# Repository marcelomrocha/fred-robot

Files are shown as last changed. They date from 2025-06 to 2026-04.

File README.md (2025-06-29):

# FRED - Friendly Robot for EDucation and Healthcare
</br></br>
<p align="center">
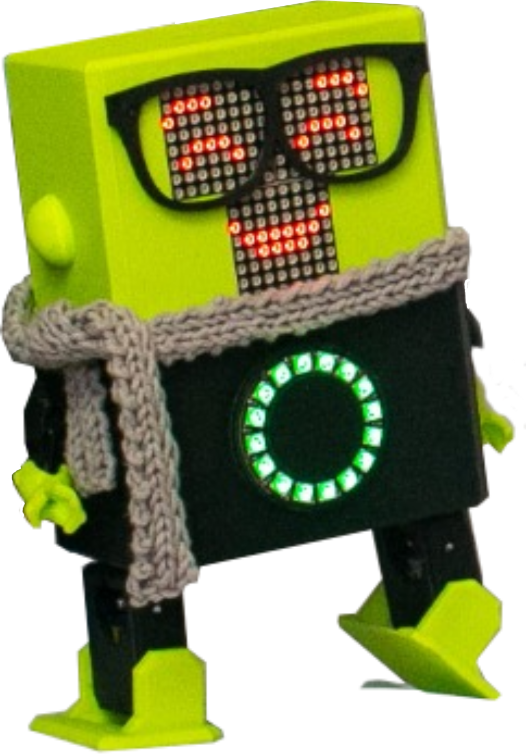
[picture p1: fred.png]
 </br></br>
<strong>Figure 1.</strong> FRED Robot - A Friendly Robot for EDucation and Healthcare.
</p>
</br></br></br>
<p align="center">
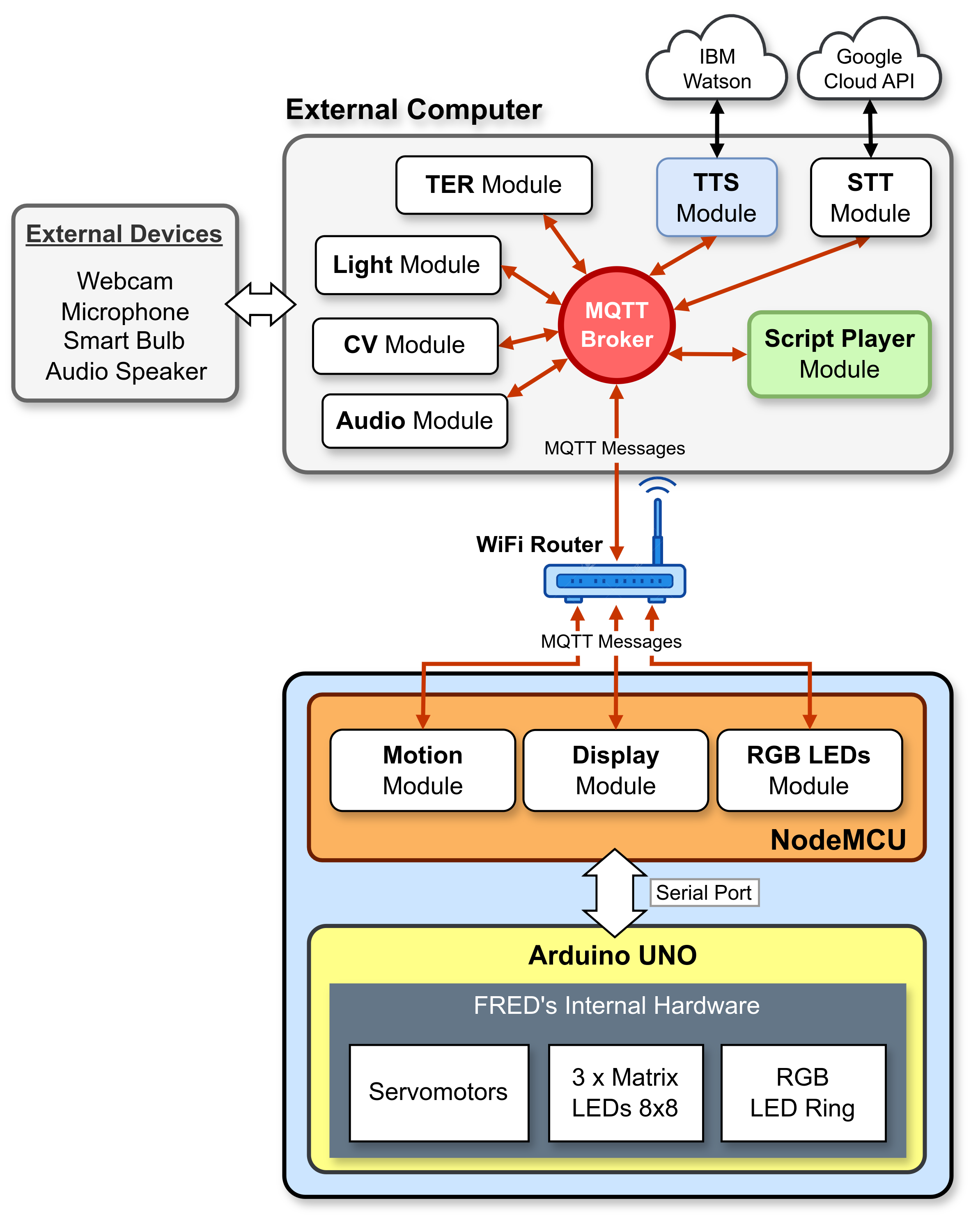
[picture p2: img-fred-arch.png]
 </br></br>
<strong>Figure 2.</strong> FRED Robot - Software Archtecture.

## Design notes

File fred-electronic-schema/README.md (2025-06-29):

# FRED - Friendly Robot for EDucation and Healthcare
## Electronic Schema Using an Arduino and ESP8266 Boards

Figure 1 shows the connection diagram for the FRED hardware components using jumper wires and a mini protoboard. The battery shown in the figure represents the 5V power supply with a minimum current capacity of 2A. All power for the FRED internal hardware system is supplied by this power supply. The diagram shown in the figure shows that the 8x8 LED arrays that make up the robot's display are connected in cascade (in series). The information for the LEDs in each array is sent through a multiplexing process, preventing the need for multiple Arduino ports to control the robot's display. The same happens with the ring of 16 RGB LEDs, whose LEDs are individually controlled by just one port on the Arduino board. The figure also shows the 4 servomotors with the indication of each one, whether it is on the left or right leg or whether it is on the right or left foot.

Recently, three **TTP223** touch sensors were added to the FRED robotics platform. These sensors were attached to the robot’s internal surfaces, on the top of its head and below both ears. Now, touching the top of FRED’s head, right in the center, for about five seconds causes the robot to look in love, turn on its LEDs in rainbow mode, and pose with its legs "broken", indicating that it has fallen in love after receiving the user’s affection. If the user also touches the area just below FRED's ears for about five seconds, the robot will smile, turn on its LEDs green and bend its right or left foot, respectively, indicating that it felt tickled by the user. In the three previous cases, after contact with the user, the robot returns to the neutral position, with a neutral look and its LEDs off (without color).

**For testing purposes only**, initially, just to test the firmware and connections, the power can come directly from the Arduino's 5V pin, with the Arduino connected to the computer's USB port.

</br>
<p align="center">
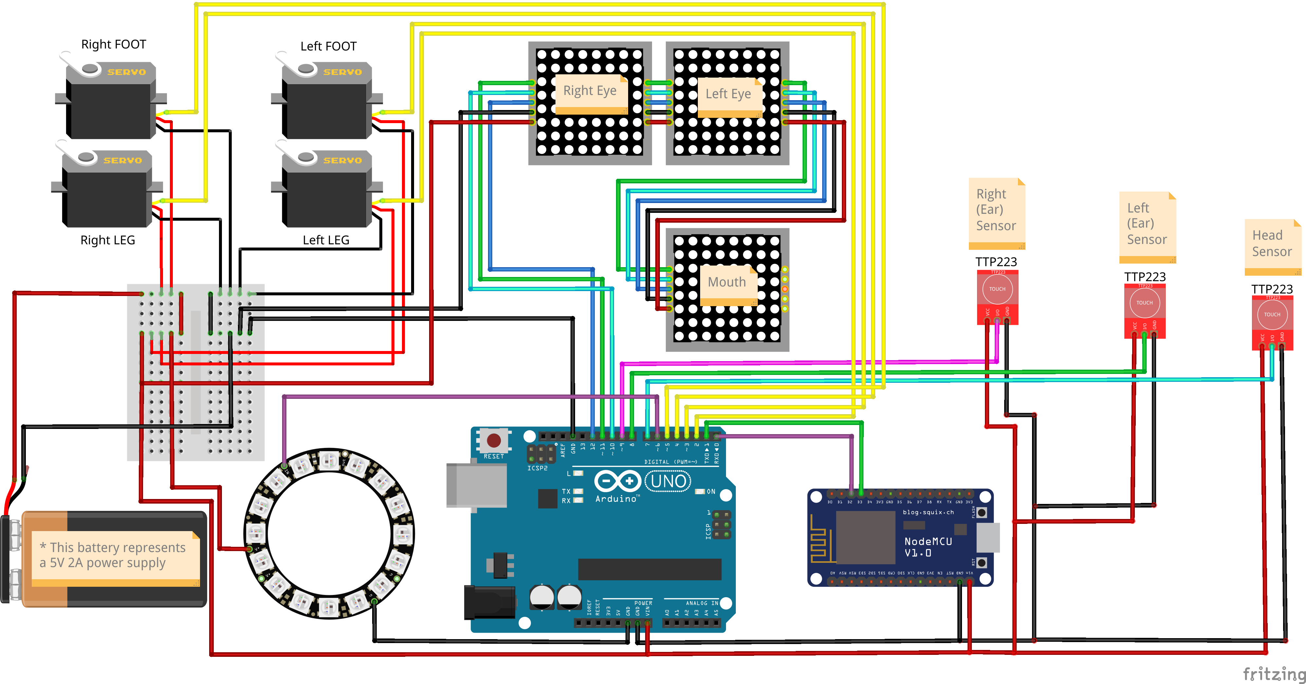
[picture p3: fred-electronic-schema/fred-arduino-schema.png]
 </br>
<strong>Figure 1.</strong> FRED Robot - Electronic Schema
</p>

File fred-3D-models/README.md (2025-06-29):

## FRED Robot - 3D parts description

Figure 1 shows the 3D models of FRED rendered in TinkerCad. Item (1) shows the 3D part of FRED's head. Item (2) shows the cover of the back of the head. Item (3) is the robot's chest. The version in the image is equivalent to the chest of the female version made to receive the pink heart. Item (4) shows the cover of the back of the chest. Item (5) shows the shoulder that must be screwed to the chest. Items (6) and (7) are, respectively, the arm and articulated hand of the robot. There is no difference between the shoulders, arms and left and right hands. Items (8) and (9) are the right and left feet. It is important to note that there is a difference between the left and right foot models. In (10) you can see two pieces of the robot's legs. These pieces use the same model, with no difference between the left and right legs. In (11) you can see the model of FRED's glasses. And finally, in item (12) you can see the model of the female glasses and the 3D heart piece that can be fitted to the female chest model.

It is important to note that in this directory there are two head models (FRED and Frida) that differ only in the size of the ears and there are two chest models (FRED and Frida). There is also a model for the 3D piece used on the female head to attach Frida's bows.

If you want to customize any element or use these models as a basis for your project, you can access them through this <a href="https://www.tinkercad.com/things/dGqDeysEWR8-copy-of-projeto-fred-versao-2023/edit" target="_blank">link</a>.

</br>
<p align="center">
 </br>
<strong>Figure 1.</strong> FRED Robot - 3D parts rendered
</p>

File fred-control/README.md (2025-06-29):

# FRED - Friendly Robot for EDucation and Healthcare
## FRED's Arduino Control Software

The software architecture of the FRED robot can be divided into two layers, high-level and low-level. The low-level layer is implemented on the Arduino UNO and ESP8266 (NodeMCU) boards inside the robot. The control software for this layer is divided into these two boards. The software running on the Arduino board is responsible for controlling and communicating with the robot's actuators, such as: the three LED arrays that represent the robot's facial expression, the RGB LED strip on the robot's chest, and the four servomotors that make up FRED's legs and feet.

</br>
<p align="center">
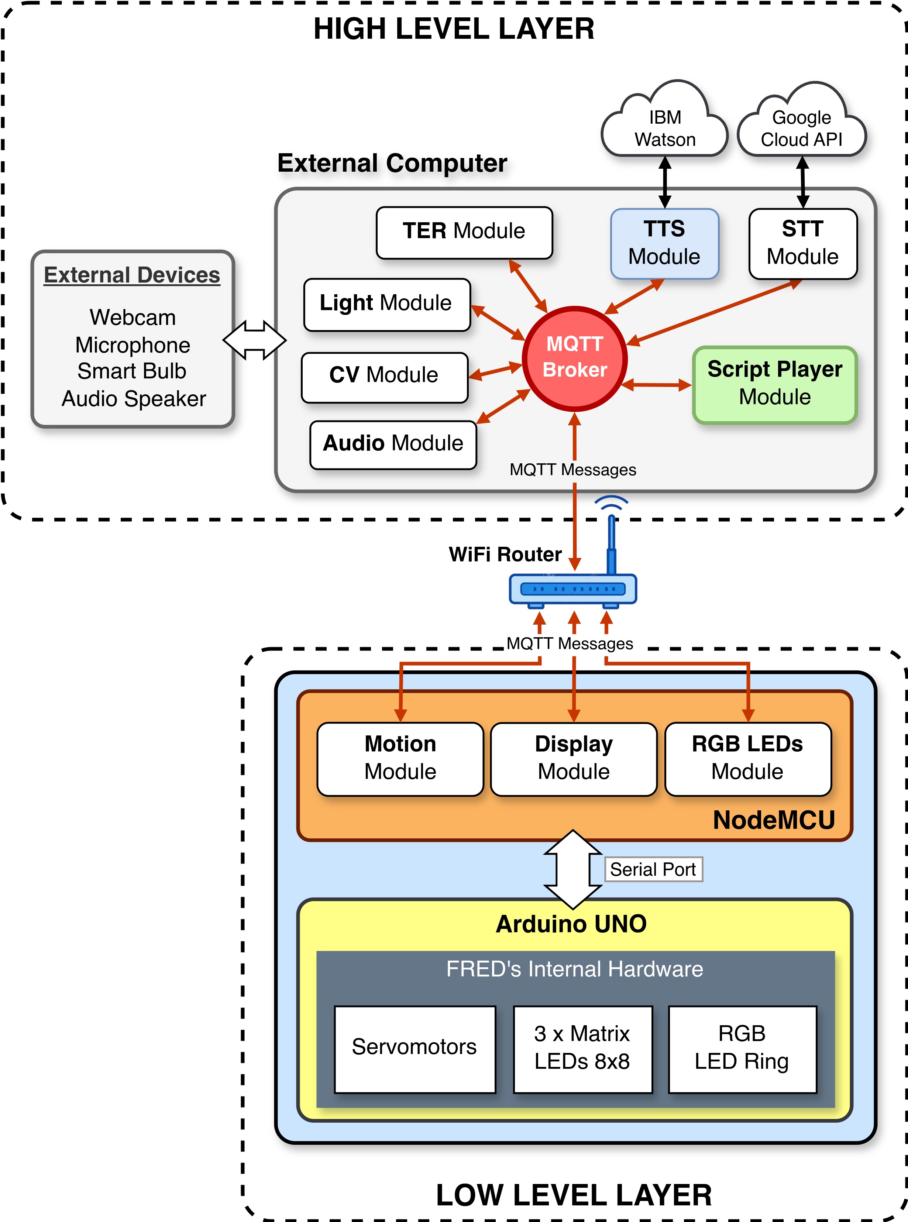
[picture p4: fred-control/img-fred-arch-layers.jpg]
 </br></br>
<strong>Figure 1.</strong> FRED Robot - Software Archtecture (LAYERS).
</br></br></br>

The FRED firmware for the Arduino board depends on two libraries, **VarSpeedServo (4)**, **LedControl (3)** and **Adafruit_NeoPixel (2)**. They are, respectively, the libraries that control the servomotors and the LED ring on the robot's chest. These libraries must be inside the **libraries folder (1)** of the Arduino IDE. These libraries are available in this directory in a compressed form. You must download the three compressed files and unzip them in the IDE's **libraries folder (1)**, as you can see in Figure 2.

</br>
<p align="center">
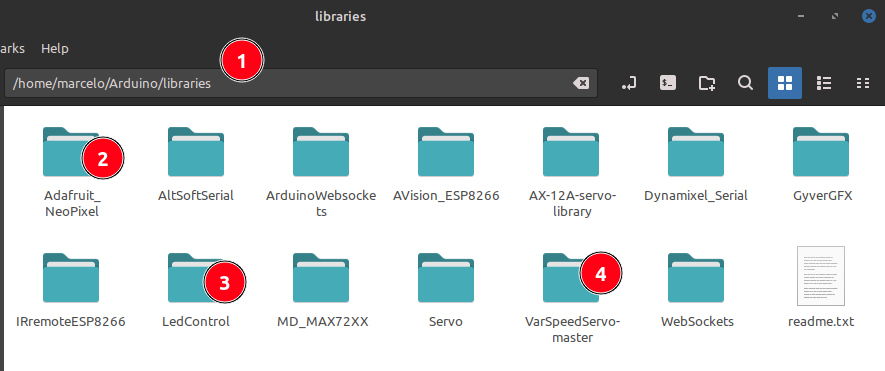
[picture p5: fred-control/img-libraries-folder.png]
 </br></br>
<strong>Figure 2.</strong> Copying and uncompressing the libraries do the Arduino libraries folder.

</br></br>
After that, the **FredControl.ino** file can be loaded into the Arduino IDE, compiled and uploaded to the Arduino UNO board.

As you can see in Figure 3, the necessary libraries are included right at the beginning of the code (1). In (2) there is the inclusion of the files **FredSymbols.h**, which contain the **array of bits** that define the design of FRED's gaze, and the files **FredControlBoy.h** and **FredControlGirl.h**, which contain some adjustments to specific parameters of the FRED and Frida robots.

</br>
<p align="center">
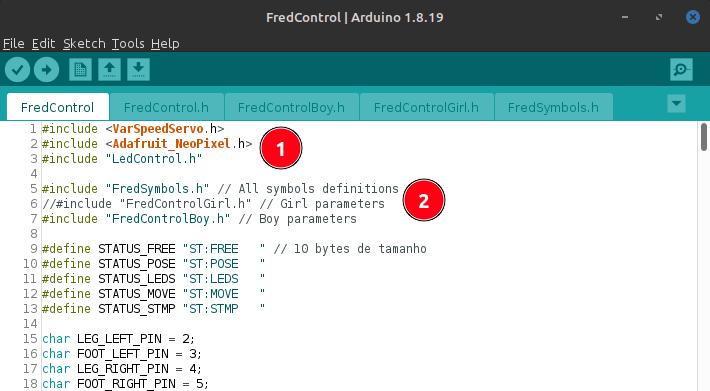
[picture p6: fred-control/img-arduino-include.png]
 </br></br>
<strong>Figure 3.</strong> Files used in Arduino's #include section.

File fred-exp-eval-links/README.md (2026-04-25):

<p align="center">
  FRED Robot
</p>

<h1 align="center">🤖 FRED Robot: Affective Expressions Evaluation</h1>

<p align="center">
  Video stimuli used in the experimental evaluation of the interaction between <b>FRED</b> and <b>Frida</b>.
</p>

<p align="center">
  <i>Low-cost affective social robot for HRI research</i>
</p>

---

> **Note:** GitHub opens links in the same tab by default. Use **Ctrl + Click** or **Cmd + Click** to open videos in a new tab.

## 📺 Video Stimuli

| Content | Access |
| :--- | :--- |
| 🎬 **Complete Interaction Video** |  |
| 🧩 **Video Block 1** |  |
| 🧩 **Video Block 2** |  |
| 🧩 **Video Block 3** |  |
| 🧩 **Video Block 4** |  |
| 🧩 **Video Block 5** |  |
| 🧩 **Video Block 6** |  |

---

## 🧠 Description of the Stimuli

The complete video presents a dialogue between the robots **FRED** and **Frida**. For evaluation purposes, the interaction was segmented into six blocks, each containing one or more affective expressions performed by the FRED robot.

These expressions were generated through the combination of nonverbal communication elements, including facial expressions, body poses, and RGB LED patterns, representing the emotions evaluated in the study: **happiness, sadness, anger, and surprise**, as well as neutral states.

Each video block was used as an independent stimulus during the experiment, allowing participants to assess the perceived intensity of each emotion.

---

## 🔗 Citation

If you use this material, please cite:

```bibtex
@phdthesis{your_reference_here,
  author = {Your Name},
  title = {Your Thesis Title},
  school = {Your Institution},
  year = {2026}
}

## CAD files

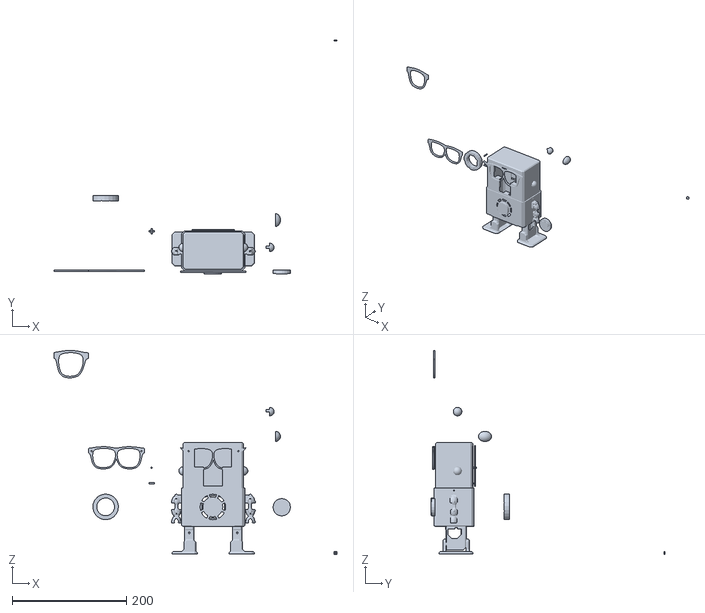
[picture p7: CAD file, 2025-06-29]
fred-3D-models/FRED-ALL-PARTS-24-9-2023.stl
496.0 x 410.0 x 357.6

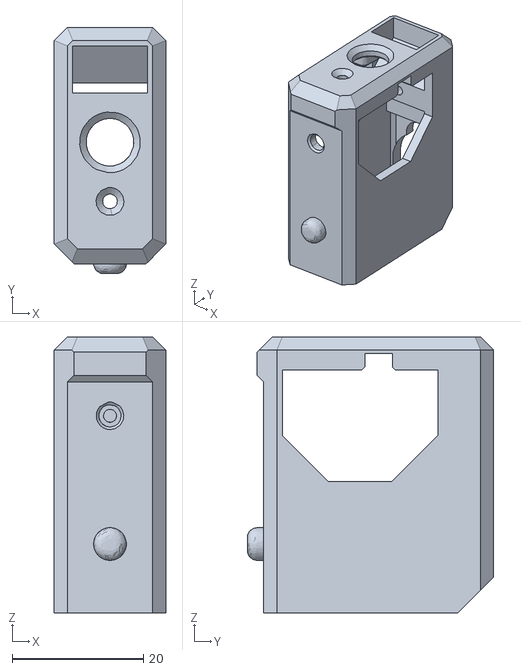
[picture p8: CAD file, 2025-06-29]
fred-3D-models/fred-leg.stl
17.0 x 37.5 x 42.0

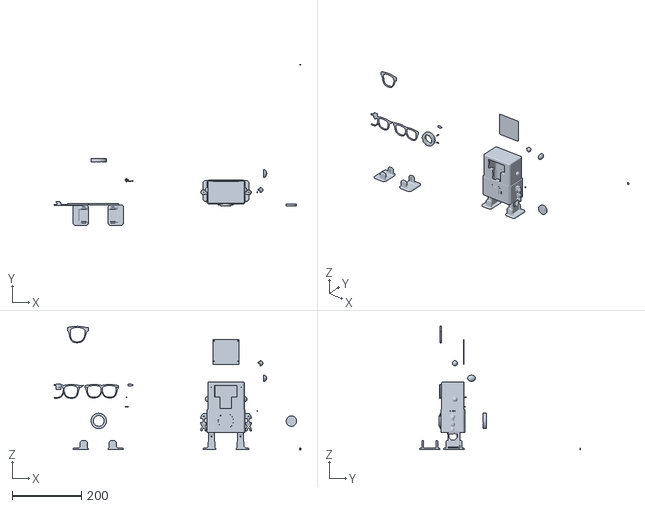
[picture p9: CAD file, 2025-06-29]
fred-3D-models/FRED-ALL-PARTS-30-9-2023.stl
715.0 x 466.2 x 357.6

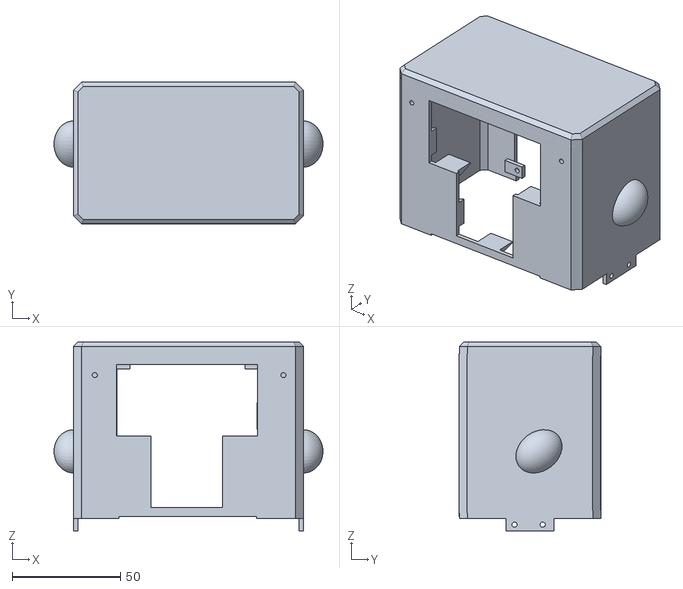
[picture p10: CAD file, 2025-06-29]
fred-3D-models/fred-boy-head.stl
124.1 x 65.4 x 87.1

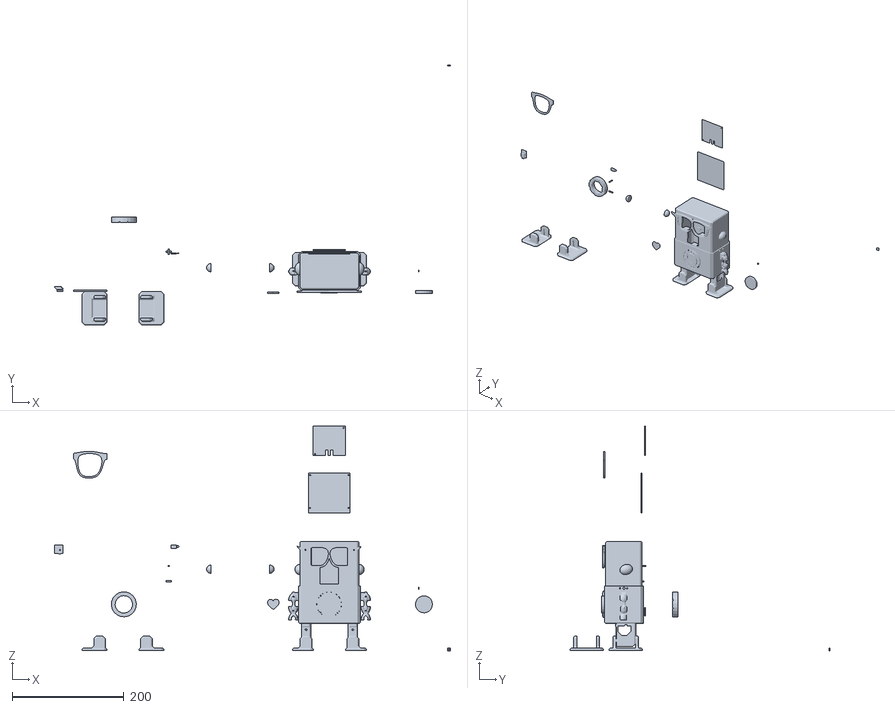
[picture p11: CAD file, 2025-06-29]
fred-3D-models/FRED-ALL-PARTS-02-10-2023.stl
709.8 x 466.2 x 403.0

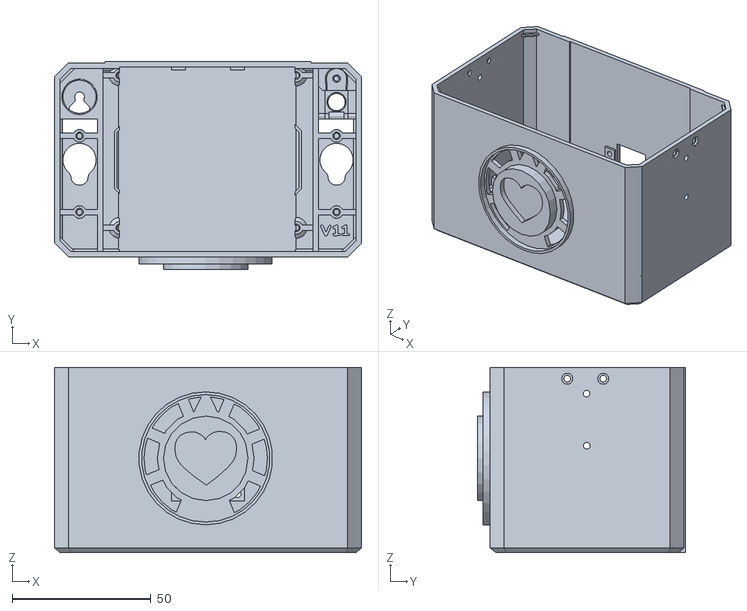
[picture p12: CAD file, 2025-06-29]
fred-3D-models/fred-girl-torax.stl
110.8 x 75.0 x 66.9

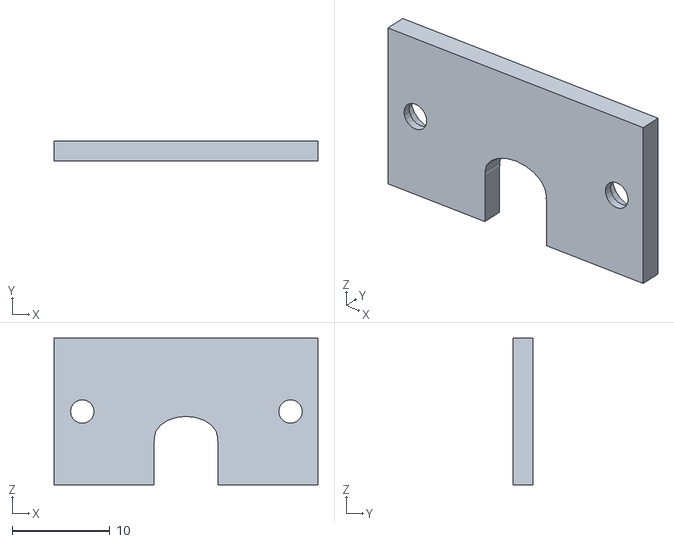
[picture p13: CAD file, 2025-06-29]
fred-3D-models/fred-tampo-torax.stl
27.0 x 2.00 x 15.0

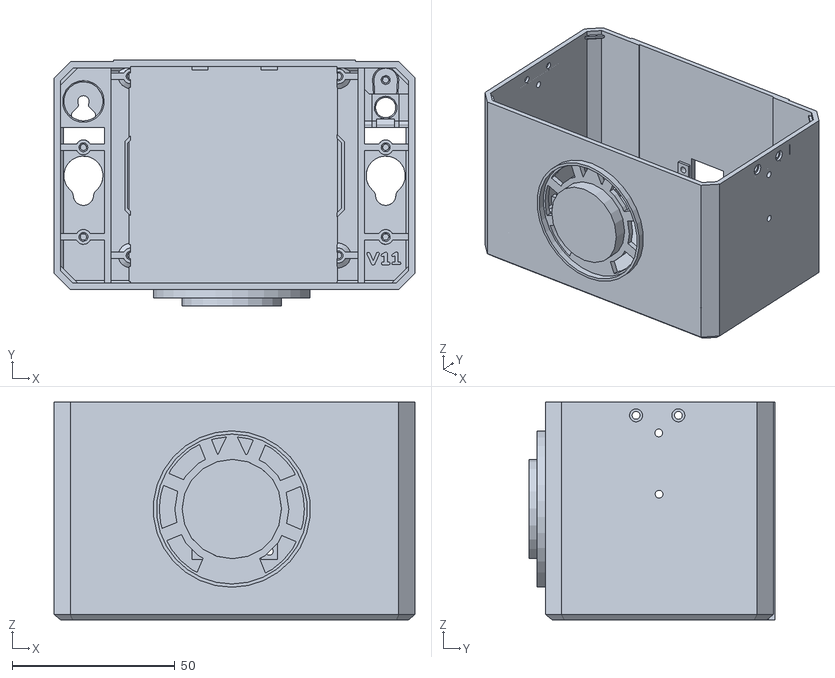
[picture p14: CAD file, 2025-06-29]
fred-3D-models/fred-boy-torax.stl
110.8 x 75.5 x 66.9

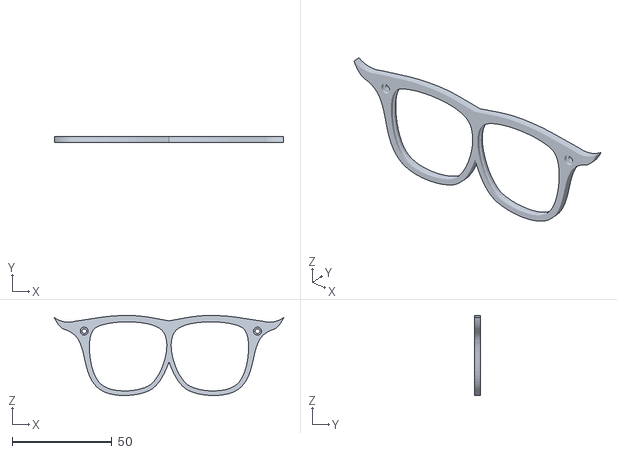
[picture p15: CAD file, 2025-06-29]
fred-3D-models/fred-girl-glasses.stl
115.0 x 3.00 x 40.2

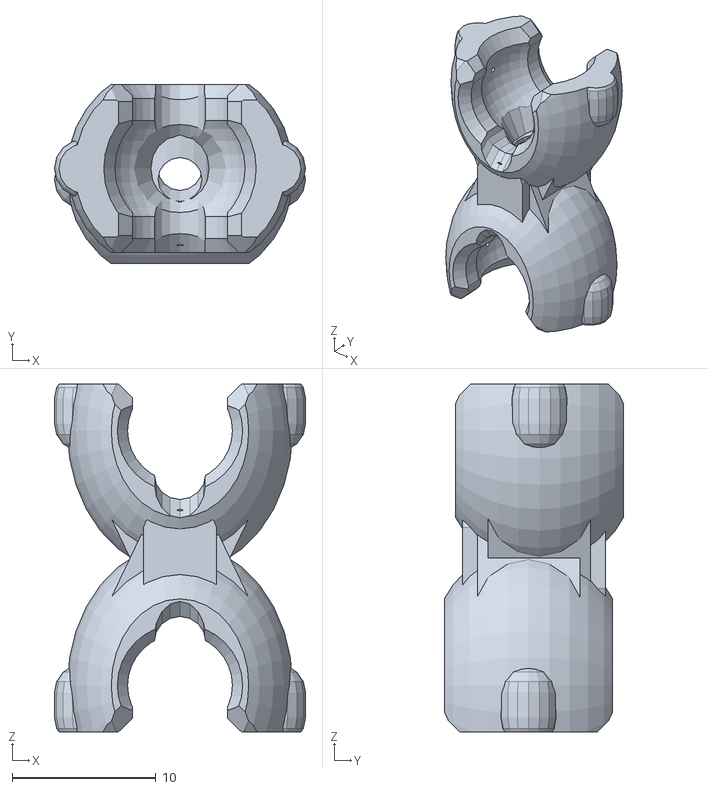
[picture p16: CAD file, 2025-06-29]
fred-3D-models/fred-hand.stl
17.5 x 12.5 x 24.2

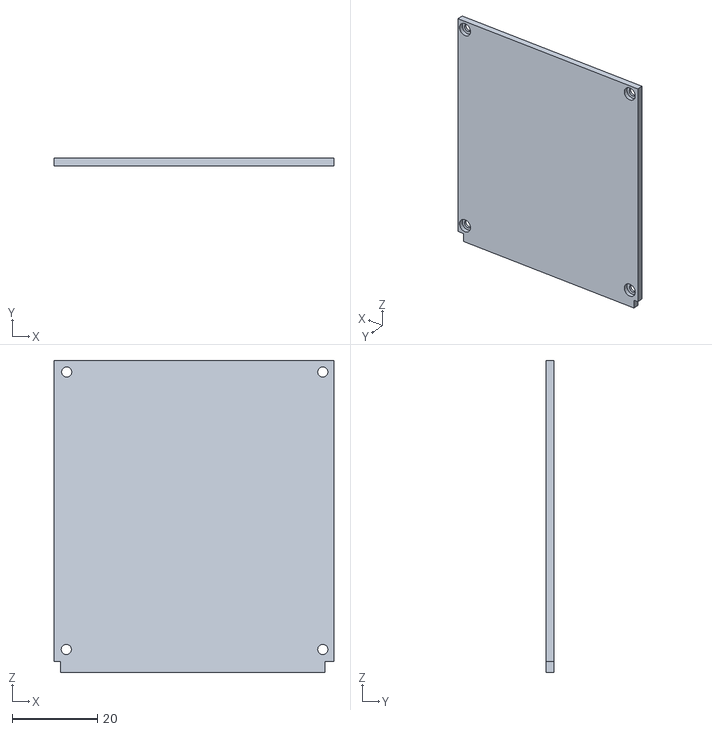
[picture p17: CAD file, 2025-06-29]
fred-3D-models/fred-tampo-head.stl
65.5 x 1.97 x 73.1

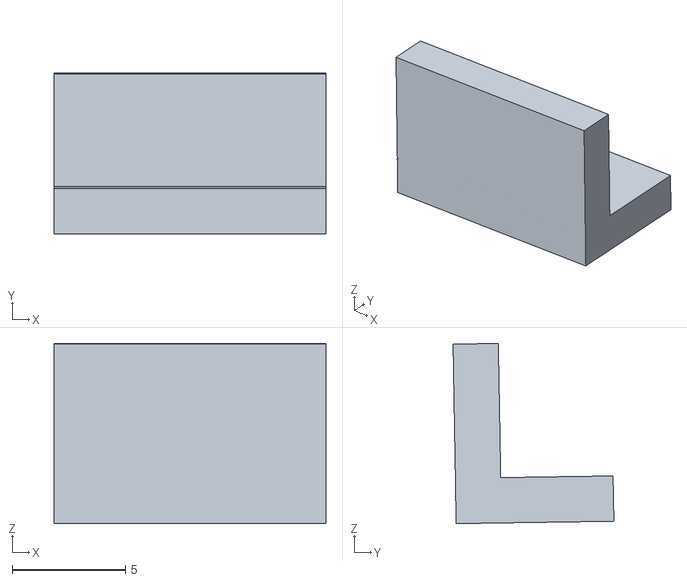
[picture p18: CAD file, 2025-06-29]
fred-3D-models/fred-girl-fixa-grampo.stl
12.0 x 7.10 x 7.95

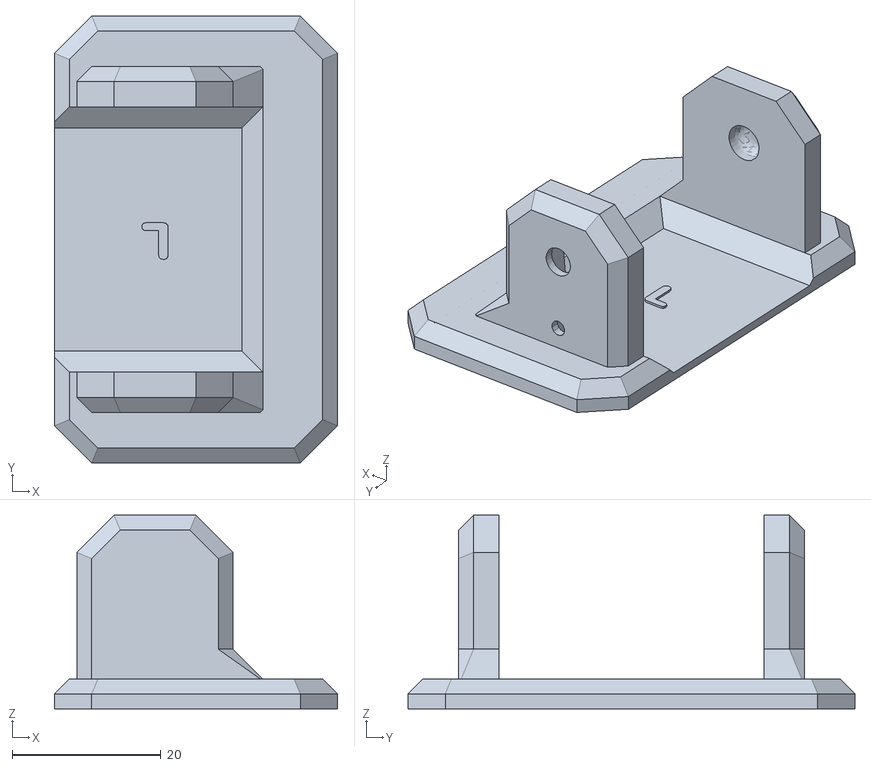
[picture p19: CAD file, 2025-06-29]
fred-3D-models/fred-left-foot-small.stl
38.0 x 60.0 x 26.0

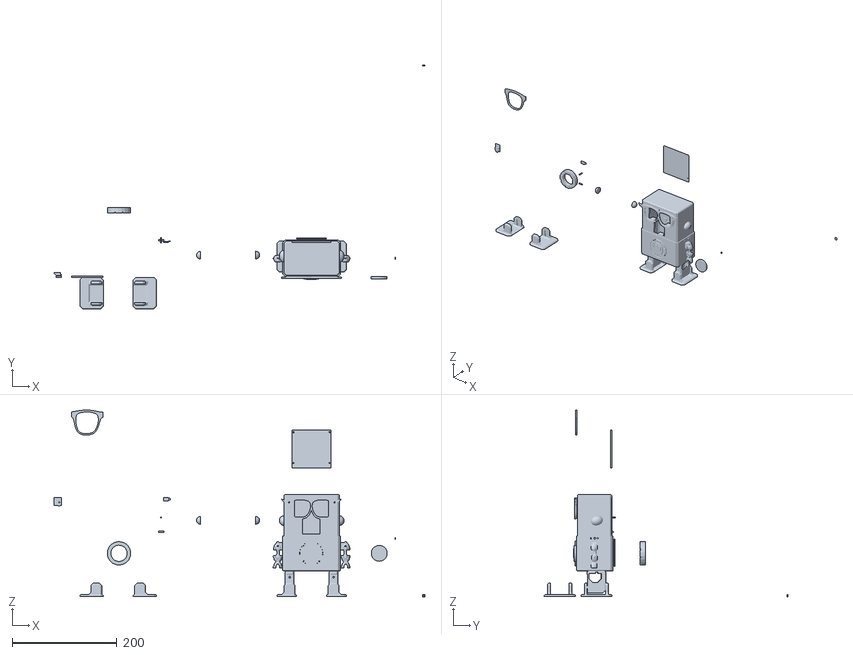
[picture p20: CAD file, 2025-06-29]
fred-3D-models/FRED-ALL-PARTS-01-10-2023.stl
709.8 x 466.2 x 357.6

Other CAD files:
fred-3D-models/fred-girl-heart.stl
fred-3D-models/fred-girl-head.stl
fred-3D-models/fred-shoulder.stl
fred-3D-models/fred-arm.stl
fred-3D-models/fred-boy-glasses.stl
fred-3D-models/fred-right-foot-small.stl

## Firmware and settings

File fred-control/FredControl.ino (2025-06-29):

#include <VarSpeedServo.h>
#include <Adafruit_NeoPixel.h>
#include "LedControl.h"
 
#include "FredSymbols.h" // All symbols definitions
#include "FredControlGirl.h" // Girl parameters
// #include "FredControlBoy.h" // Boy parameters

#define STATUS_FREE "ST:FREE   " // 10 bytes de tamanho
#define STATUS_POSE "ST:POSE   "
#define STATUS_LEDS "ST:LEDS   "
#define STATUS_MOVE "ST:MOVE   "
#define STATUS_STMP "ST:STMP   "

char LEG_LEFT_PIN = 2;
char FOOT_LEFT_PIN = 3;
char LEG_RIGHT_PIN = 4;
char FOOT_RIGHT_PIN = 5;

// Sensores de toque
int TOUCH_HEAD_PIN = 7;
int TOUCH_HEAD_VALUE = 0;
int TOUCH_LEFT_PIN = 8;
int TOUCH_LEFT_VALUE = 0;
int TOUCH_RIGHT_PIN = 9;
int TOUCH_RIGHT_VALUE = 0;

// variaveis de estado do robô
char veloc_srv = 40; // servo movement velocity
char state_pose = NULL; // estado da posição inicial
char state_expression = NULL; // estado da expressão (display) inicial
char state_exp_aux = NULL; // variavel mantem seu estado mesmo depois da funcao terminar
char state_led = NULL; // estado do anel de leds

unsigned long eye_blinking_mills = millis(); // eye blinking
unsigned long eye_blinking_delay = 5000; // delay eye blinking
unsigned long foot_mills = millis(); // foot effect
unsigned long foot_delay = 5000; // delay foot effect
unsigned long led_speech_mills = millis(); // LED speech effect
unsigned long led_speech_delay = 400; // LED speech delay effect

VarSpeedServo leg_left_srv;
VarSpeedServo foot_left_srv;
VarSpeedServo leg_right_srv;
VarSpeedServo foot_right_srv;

/*
 Now we need a LedControl to work with.
 ***** These pin numbers will probably not work with your hardware *****
 pin 12 is connected to the DataIn (azul ou verde)
 pin 11 is connected to the CLK     (cinza ou marron)
 pin 10 is connected to LOAD    (branco ou laranja)
 We have 3  MAX72XX.
 */
LedControl lc=LedControl(12,11,10,3);
int delay_leds = 200; // determina a velocidade do efeito dos leds. Quanto maior o valor mais lento.

// defining expressions vars
Expression fred;
Expression in_love;
Expression broken;
Expression neutral;
Expression pleased;
Expression happy;
Expression sad;
Expression angry, angry2;
Expression surprised, surprised2;
Expression afraid;

// Parameter 1 = number of pixels in strip
// Parameter 2 = pin number (most are valid)
// Parameter 3 = pixel type flags, add together as needed:
//   NEO_KHZ800  800 KHz bitstream (most NeoPixel products w/WS2812 LEDs)
//   NEO_KHZ400  400 KHz (classic 'v1' (not v2) FLORA pixels, WS2811 drivers)
//   NEO_GRB     Pixels are wired for GRB bitstream (most NeoPixel products)
//   NEO_RGB     Pixels are wired for RGB bitstream (v1 FLORA pixels, not v2)

#define PIN 6
Adafruit_NeoPixel ring = Adafruit_NeoPixel(16, PIN, NEO_GRB + NEO_KHZ800);
 

void setup() {

  Serial.begin(9600);

  pinMode(TOUCH_HEAD_PIN, INPUT);
  pinMode(TOUCH_LEFT_PIN, INPUT);
  pinMode(TOUCH_RIGHT_PIN, INPUT);

  fred.right_eye = fr;
  fred.left_eye = ed;
  fred.mouth = heart;

  in_love.right_eye = r_eye_in_love;
  in_love.left_eye = l_eye_in_love;
  in_love.mouth = m_in_love;

  broken.right_eye = r_eye_broken;
  broken.left_eye = l_eye_in_broken;
  broken.mouth = m_in_broken;

  neutral.right_eye = r_eye_neutral;
  neutral.left_eye = l_eye_neutral;
  neutral.mouth = m_neutral;

  pleased.right_eye = r_eye_pleased;
  pleased.left_eye = l_eye_pleased;
  pleased.mouth = m_pleased;

  happy.right_eye = r_eye_happy;
  happy.left_eye = l_eye_in_happy;
  happy.mouth = m_in_happy;

  sad.right_eye = r_eye_sad;
  sad.left_eye = l_eye_in_sad;
  sad.mouth = m_in_sad;

  angry.right_eye = r_eye_angry;
  angry.left_eye = l_eye_in_angry;
  angry.mouth = m_in_angry;

  angry2.right_eye = r_eye_angry2;
  angry2.left_eye = l_eye_in_angry2;
  angry2.mouth = m_in_angry2;

  surprised.right_eye = r_eye_surprised;
  surprised.left_eye = l_eye_in_surprised;
  surprised.mouth = m_in_surprised;

  surprised2.right_eye = r_eye_surprised;
  surprised2.left_eye = l_eye_in_surprised;
  surprised2.mouth = m_in_surprised2;

  afraid.right_eye = r_eye_afraid;
  afraid.left_eye = l_eye_in_afraid;
  afraid.mouth = m_in_afraid;
  
    /*
   The MAX72XX is in power-saving mode on startup,
   we have to do a wakeup call
   */
  lc.shutdown(0,false);
  lc.shutdown(1,false);
  lc.shutdown(2,false);
  /* Set the brightness to a medium values */
  lc.setIntensity(0,1);
  lc.setIntensity(1,1);
  lc.setIntensity(2,1);
  /* and clear the display */
  lc.clearDisplay(0);
  lc.clearDisplay(1);
  lc.clearDisplay(2);

  ring.begin();
  ring.setBrightness(5); //adjust brightness here
  ring.show(); // Initialize all pixels to 'off'
  
  expression_show(fred); 
  delay(3000);
  colorWipe(ring.Color(255, 0, 0), delay_leds, 'r'); // Black (off)
  state_led = 'r';
  expression_show(broken);
  state_expression = 'b';
  servos_attach();
  pose_init('1');
}
 
void loop() {
  run();
}

///////////////////////////////////////////////////////////////// Função principal que roda as outras funções //////////////////////////
// looping principal
void run(){
  while (1){
    processa_serial_port(); // 
    blinking_eyes(); // pisca olhos aleatoreamente
    anim_feet(); // move os pés do FRED aleatoreamente
    sense_touch(); // Verifica se o robo foi tocado e muda o seu estado, executando a animaçao
  }
}


///////////////////////////////////////////////////////////////// Funções para os LEDs RGB ////////////////////////////////////////
// Fill the dots one after the other with a color
void colorWipe(uint32_t c, uint8_t wait, char type) {
  if (state_expression == 'T') {
    state_led = type;
    servos_attach();
  }
  else {
    servos_detach();
    delay(1); // evita o truncamento no envio pela porta serial
    //Serial.print(STATUS_LEDS);
    for(uint16_t i=0; i<ring.numPixels() / 4 + 1; i++) {
      ring.setPixelColor(4 - i, c);
      ring.setPixelColor(4 + i, c);
      ring.setPixelColor(12 - i, c);
      ring.setPixelColor(12 + i, c);
      ring.show();
      delay(wait);
//      blinking_eyes();
    }
    delay(1);
    //Serial.print(STATUS_FREE);
  }
  state_led = type;
  servos_attach();
}

// efeito no LED usado na fala do robô
void colorSpeech(uint32_t c, bool type) {
  servos_detach();
  if (type == false){ // acende os LEDS pares
    for(uint16_t i=0; i<=ring.numPixels(); i++) {
        if (i % 3 == 0){
          ring.setPixelColor(i, c);
//          ring.show();
        }
        else {
          ring.setPixelColor(i, (0, 0, 0));
//          ring.show();
        }
        ring.show();
    }
  }
  else { // acende os LEDs ímpares
    for(uint16_t i=0; i<=ring.numPixels(); i++) {
        if (i % 3 != 0){
          ring.setPixelColor(i, c);
        }
        else {
          ring.setPixelColor(i, (0, 0, 0));
        }
        ring.show();
    }
  }
}
 

void rainbow(uint8_t wait, char type) {
  servos_detach();
  delay(1); // evita o truncamento no envio pela porta serial
  //Serial.print(STATUS_LEDS);
  uint16_t i, j;
  // primeira vez
  for(j=0; j<256; j++) {
    for(i=0; i<ring.numPixels(); i++) {
      ring.setPixelColor(i, Wheel((i+j) & 255));
    }
    ring.show();
    delay(wait);
  }
  state_led = type;
  delay(1);
  //Serial.print(STATUS_FREE);
  servos_attach();
}
 
// Slightly different, this makes the rainbow equally distributed throughout
void rainbowCycle(uint8_t wait) {
  servos_detach();
  delay(1); // evita o truncamento no envio pela porta serial
  //Serial.print(STATUS_LEDS);
  uint16_t i, j;
  for(j=0; j<256*5; j++) { // 5 cycles of all colors on wheel
    for(i=0; i< ring.numPixels(); i++) {
      ring.setPixelColor(i, Wheel(((i * 256 / ring.numPixels()) + j) & 255));
    }
    ring.show();
    delay(wait);
  }
  delay(1);
  //Serial.print(STATUS_FREE);
  servos_attach();
}
 
// Input a value 0 to 255 to get a color value.
// The colours are a transition r - g - b - back to r.
uint32_t Wheel(byte WheelPos) {
  if(WheelPos < 85) {
   return ring.Color(WheelPos * 3, 255 - WheelPos * 3, 0);
  } else if(WheelPos < 170) {
   WheelPos -= 85;
   return ring.Color(255 - WheelPos * 3, 0, WheelPos * 3);
  } else {
   WheelPos -= 170;
   return ring.Color(0, WheelPos * 3, 255 - WheelPos * 3);
  }
}

///////////////////////////////////////////////////////////////// Função que mostra uma Expressão no DISPLAY ///////////////////////////////
// show an expression
void expression_show(Expression expression){
  char state_expression_aux = state_expression; // para verificar se state_expression igual a "T"
  if (expression.right_eye == fr)
    state_expression = 'f';
  else if (expression.right_eye == r_eye_in_love)
    state_expression = 'i';
  else if (expression.right_eye == r_eye_broken)
    state_expression = 'b';
  else if (expression.right_eye == r_eye_neutral)
    state_expression = 'n';
  else if (expression.right_eye == r_eye_neutral_blink)
    state_expression = '-';
  else if (expression.right_eye == r_eye_pleased)
    state_expression = 'p';
  else if (expression.right_eye == r_eye_pleased_blink)
    state_expression = '-';
  else if (expression.right_eye == r_eye_happy)
    state_expression = 'h';
  else if (expression.right_eye == r_eye_sad)
    state_expression = 's';
  else if (expression.right_eye == r_eye_angry)
    state_expression = 'a';
  else if (expression.right_eye == r_eye_angry2)
    state_expression = 'A';
  else if (expression.right_eye == r_eye_surprised)
    state_expression = 'u';
  else if (expression.right_eye == r_eye_afraid)
    state_expression = 'r';
  matrix0_write(expression.right_eye);
  matrix1_write(expression.left_eye);
  matrix2_write(expression.mouth);
  if (state_expression_aux == 'T') state_expression = state_expression_aux; // isso tem influência nas animações dos leds quendo falando.
}


///////////////////////////////////////////////////////////////// Funções de controle individual de cada matriz 8x8 //////////////////////////
void matrix0_write(char * symbol)
{
  lc.setRow(0,0,symbol[0]);
  lc.setRow(0,1,symbol[1]);
  lc.setRow(0,2,symbol[2]);
  lc.setRow(0,3,symbol[3]);
  lc.setRow(0,4,symbol[4]);
  lc.setRow(0,5,symbol[5]);
  lc.setRow(0,6,symbol[6]);
  lc.setRow(0,7,symbol[7]);
}

void matrix1_write(char * symbol)
{
  lc.setRow(1,0,symbol[0]);
  lc.setRow(1,1,symbol[1]);
  lc.setRow(1,2,symbol[2]);
  lc.setRow(1,3,symbol[3]);
  lc.setRow(1,4,symbol[4]);
  lc.setRow(1,5,symbol[5]);
  lc.setRow(1,6,symbol[6]);
  lc.setRow(1,7,symbol[7]);
}

void matrix2_write(char * symbol)
{
  lc.setRow(2,0,symbol[0]);
  lc.setRow(2,1,symbol[1]);
  lc.setRow(2,2,symbol[2]);
  lc.setRow(2,3,symbol[3]);
  lc.setRow(2,4,symbol[4]);
  lc.setRow(2,5,symbol[5]);
  lc.setRow(2,6,symbol[6]);
  lc.setRow(2,7,symbol[7]);
}

///////////////////////////////////////////////////////////////// Funções que controlam as POSES /////////////////////////////////////////
// pose init
void pose_init(char type){ // alinha pernas e pés (tipo 1 = envia info de pose para o nodemcu)
  if (state_pose != 'i') {
    servos_attach();
    char veloc_aux = veloc_srv; //salva o valor da velocidade global
    veloc_srv = 45; // define velocity for init  
    if (type == '1'){ // (tipo 1 = envia info de pose para o nodemcu)
      delay(1); // evita o truncamento no envio pela porta serial
      //Serial.print(STATUS_POSE);
    }
    leg_left_srv.write(LEG_LEFT_EQ, veloc_srv);
    leg_right_srv.write(LEG_RIGHT_EQ, veloc_srv);
    while (leg_left_srv.isMoving()){ delay(1); }
    while (leg_right_srv.isMoving()){ delay(1); }
    foot_left_srv.write(FOOT_LEFT_EQ, veloc_srv);
    foot_right_srv.write(FOOT_RIGHT_EQ, veloc_srv);
    while (foot_left_srv.isMoving()){ delay(1); }
    while (foot_right_srv.isMoving()){ delay(1); }
    state_pose = 'i';
    veloc_srv = veloc_aux;
    foot_mills = millis(); // reinicia o contador para a animação aleatória dos peś
    if (type == '1'){ // (tipo 1 = envia info de pose para o nodemcu)
      delay(100); // evita o truncamento no envio pela porta serial
      //Serial.print(STATUS_FREE);
    }
  }
}

// pose up
void pose_up(char type){
  if (state_pose != 'l' || state_pose != 'L' || state_pose != 'r' || state_pose != 'r' && state_pose || 'u'){
    char velo_aux = veloc_srv; // saves global velocity
    veloc_srv = 60;
    delay(1); // evita o truncamento no envio pela porta serial
    //Serial.print(STATUS_POSE);
    pose_init('2'); // acerta a postura antes pose sem desligar os servos
    if (type == 'l'){
      foot_left_srv.write(140, veloc_srv, true);
      state_pose = 'l'; // state up left
    }
    else if (type == 'L'){
      foot_left_srv.write(30, veloc_srv, true);
      state_pose = 'L'; // state up left
    }
    else if (type == 'r'){
      foot_right_srv.write(25, veloc_srv, true);
      state_pose = 'r'; // state up right
    }
    else if (type == 'R'){
      foot_right_srv.write(140, veloc_srv, true);
      state_pose = 'R'; // state up right
    }
    else if (type == 'u'){ //type = 'u'
      veloc_srv = 70;
      foot_left_srv.write(130, veloc_srv, false);
      foot_right_srv.write(35, veloc_srv, false);
      
      while (foot_right_srv.isMoving()){ delay(1); }
      while (foot_left_srv.isMoving()){ delay(1); }
      state_pose = 'u'; // state up
    }
    servos_detach();
    veloc_srv = velo_aux;
    foot_mills = millis(); // reinicia o contador para o movimento automático dos pés
    delay(100);
    //Serial.print(STATUS_FREE);
  }
}

// pose down broken
void pose_down(char param){
  if (state_pose != 'd' && state_pose != 'D'){
    char velo_aux = veloc_srv; // saves global velocity
    if (param == 'd')
      veloc_srv = 25; // more slow
    else if (param == 'D')
      veloc_srv = 50; // more fast
    delay(1); // evita o truncamento no envio pela porta serial
    //Serial.print(STATUS_POSE);
    pose_init('2'); // acerta a postura antes pose sem desligar os servos
    //servos_attach();
    foot_right_srv.write(155, veloc_srv);
    foot_left_srv.write(20, veloc_srv);
    while (foot_right_srv.isMoving()){ delay(1); }
    while (foot_left_srv.isMoving()){ delay(1); }
    //delay(500);
    //servos_detach();
    state_pose = 'd'; // state up
    veloc_srv = velo_aux;
    foot_mills = millis(); // reinicia o contador para o movimento automático dos pés
    delay(100); // evita o truncamento no envio pela porta serial
    //Serial.print(STATUS_FREE);
  }
}

///////////////////////////////////////////////////////////////// Funções de controle do MOVIMENTO ///////////////////////////////////////
// moving forward
void move_forward(char cycles){
  delay(1); // evita o truncamento no envio pela porta serial
  //Serial.print(STATUS_MOVE);
  pose_init('2'); // acerta a posição inicial sem desligar os servos
  char velo_aux = veloc_srv; // saves global velocity
  veloc_srv = 70;
  state_pose = 'm'; // muda o estado do robô para algum tipo de movimentação
  servos_attach();
  while (cycles > 0){
    leg_right_srv.write(40, veloc_srv, true);
    foot_right_srv.write(60, veloc_srv, true);
    leg_right_srv.write(LEG_RIGHT_EQ, veloc_srv, true);
    foot_right_srv.write(FOOT_LEFT_EQ, veloc_srv, true);
    leg_left_srv.write(135, veloc_srv, true);
    foot_left_srv.write(110, veloc_srv, true);
    leg_left_srv.write(LEG_LEFT_EQ, veloc_srv, true);
    foot_left_srv.write(FOOT_LEFT_EQ, veloc_srv, true);
    cycles -= 1;
  }
  pose_init("2"); // acerta a posição inicial e desliga os servos
  delay(100);
  //Serial.print(STATUS_FREE);
  state_pose = 'i';
  veloc_srv = velo_aux;
  foot_mills = millis(); // reinicia o contador para o movimento automático dos pés
}


// moving backward
void move_backward(char cycles){
  pose_init('2'); // acerta a posição inicial sem desligar os servos
  char velo_aux = veloc_srv; // saves global velocity
  veloc_srv = 70;
  servos_attach();
  delay(500); // evita o truncamento no envio pela porta serial
  //Serial.print(STATUS_MOVE);
  state_pose = 'm'; // muda o estado do robô para algum tipo de movimentação
  while (cycles > 0){
    leg_right_srv.write(130, veloc_srv, true); // 35
    //while (leg_right_srv.isMoving()){ delay(1); }
    foot_right_srv.write(60, veloc_srv, true); //45
    //while (foot_right_srv.isMoving()){ delay(1); }
    leg_right_srv.write(LEG_RIGHT_EQ, veloc_srv, true);
    foot_right_srv.write(FOOT_LEFT_EQ, veloc_srv, true);

    leg_left_srv.write(55, veloc_srv, true);
    //while (leg_left_srv.isMoving()){ delay(1); }
    foot_left_srv.write(110, veloc_srv, true); //135
    //while (foot_left_srv.isMoving()){ delay(1); }
    leg_left_srv.write(LEG_LEFT_EQ, veloc_srv, true);
    //while (leg_left_srv.isMoving()){ delay(1); }
    foot_left_srv.write(FOOT_LEFT_EQ, veloc_srv, true);
    //while (foot_left_srv.isMoving()){ delay(1); }
    cycles -= 1;
  }
  pose_init('2'); // acerta a posição inicial e desliga os servos
  delay(100);
  //Serial.print(STATUS_FREE);
  state_pose = 'i';
  veloc_srv = velo_aux;
  foot_mills = millis(); // reinicia o contador para o movimento automático dos pés
}


// move left
void move_left(char cycles){
  delay(1); // evita o truncamento no envio pela porta serial
  //Serial.print(STATUS_MOVE);
  pose_init('2'); // acerta a posição inicial sem desligar os servos
  char velo_aux = veloc_srv; // saves global velocity
  veloc_srv = 70;
  servos_attach();
  state_pose = 'm'; // muda o estado do robô para algum tipo de movimentação
  while (cycles > 0){
    foot_right_srv.write(150, veloc_srv, true);
    foot_right_srv.write(FOOT_RIGHT_EQ-5, veloc_srv, true); 
    cycles -= 1;
  }
  foot_left_srv.write(FOOT_LEFT_EQ, veloc_srv, true);
  pose_init('2'); // acerta a posição inicial e desliga os servos
  state_pose = 'i';
  veloc_srv = velo_aux;
  foot_mills = millis(); // reinicia o contador para o movimento automático dos pés
  delay(100);
  //Serial.print(STATUS_FREE);
} 


// move right
void move_right(char cycles){
  delay(1); // evita o truncamento no envio pela porta serial
  //Serial.print(STATUS_MOVE);
  pose_init('2'); // acerta a posição inicial sem desligar os servos
  char velo_aux = veloc_srv; // saves global velocity
  veloc_srv = 70;
  servos_attach();
  state_pose = 'm'; // muda o estado do robô para algum tipo de movimentação
  while (cycles > 0){
    foot_left_srv.write(20, veloc_srv, true);
    foot_left_srv.write(FOOT_LEFT_EQ, veloc_srv, true); 

    cycles -= 1;
  }
  foot_right_srv.write(FOOT_RIGHT_EQ, veloc_srv, true);
  pose_init('2'); // acerta a posição inicial e desliga os servos
  delay(100); // evita o truncamento no envio pela porta serial
  //Serial.print(STATUS_FREE);
  state_pose = 'i';
  veloc_srv = velo_aux;
  foot_mills = millis(); // reinicia o contador para o movimento automático dos pés
}


// move left moon
void move_left_moon(char cycles){
  delay(1); // evita o truncamento no envio pela porta serial
  //Serial.print(STATUS_MOVE);
  pose_init('2'); // acerta a posição inicial sem desligar os servos
  char velo_aux = veloc_srv; // saves global velocity
  veloc_srv = 80;
  servos_attach();
  state_pose = 'm'; // muda o estado do robô para algum tipo de movimentação
  while (cycles > 0){
    foot_right_srv.write(30, veloc_srv, true);
    foot_left_srv.write(130, veloc_srv, true);
    foot_right_srv.write(FOOT_RIGHT_EQ, veloc_srv, true);
    foot_left_srv.write(FOOT_LEFT_EQ, veloc_srv, true);
    cycles -= 1;
  }
  pose_init('2'); // acerta a posição inicial e desliga os servos
  delay(100); // evita o truncamento no envio pela porta serial
  //Serial.print(STATUS_FREE);
  state_pose = 'i';
  veloc_srv = velo_aux;
  foot_mills = millis(); // reinicia o contador para o movimento automático dos pés 
}


// move right moon
void move_right_moon(char cycles){
  delay(1); // evita o truncamento no envio pela porta serial
  //Serial.print(STATUS_MOVE);
  pose_init('2'); // acerta a posição inicial sem desligar os servos
  char velo_aux = veloc_srv; // saves global velocity
  veloc_srv = 80;
  servos_attach();
  state_pose = 'm'; // muda o estado do robô para algum tipo de movimentação
  while (cycles > 0){
    foot_left_srv.write(140, veloc_srv, true);
    foot_right_srv.write(40, veloc_srv, true);
    foot_left_srv.write(FOOT_LEFT_EQ, veloc_srv, true);
    foot_right_srv.write(FOOT_RIGHT_EQ, veloc_srv, true);
    cycles -= 1;
  }
  pose_init('2'); // acerta a posição inicial e desliga os servos
  delay(100);
  //Serial.print(STATUS_FREE);
  state_pose = 'i';
  veloc_srv = velo_aux;
  foot_mills = millis(); // reinicia o contador para o movimento automático dos pés
}


// moon walker left and right
void move_moon_walk(char cycles){ // só move os pés, não usa a perna
  delay(1); // evita o truncamento no envio pela porta serial
  //Serial.print(STATUS_MOVE);
  pose_init('2'); // acerta a posição inicial sem desligar os servos
  servos_attach();
  char velo_aux = veloc_srv; // saves global velocity
  veloc_srv = 80;
  state_pose = 'm'; // muda o estado do robô para algum tipo de movimentação
  while (cycles > 0){
    move_left_moon(2);
    move_right_moon(2);
    cycles -= 1;
  }
  pose_init('2'); // acerta a posição inicial e desliga os servos
  delay(100);
  //Serial.print(STATUS_FREE);
  state_pose = 'i';
  veloc_srv = velo_aux;
  foot_mills = millis(); // reinicia o contador para o movimento automático dos pés
}
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

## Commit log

2025-06-29 Uploading files.
    [FRED-ALL-PARTS-01-10-2023.stl, FRED-ALL-PARTS-02-10-2023.stl, FRED-ALL-PARTS-24-9-2023.stl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]
2025-10-25 Vibration motor added to FRED.
    [FredControl.ino]
2025-10-25 Updated schematic.
    Now we have the vibration motor added to the robot head.
2025-10-25 Fritzing file added.
    [(fred) protoboard (with touch and vib motor).fzz]
2025-10-26 Vibration motor removed...
2025-10-26 Protoboard image updated.
    [(fred) protoboard (with touch and vib motor).fzz]
2026-06-10 Atualização dos níveis de expressão (LEDs) do FRED.
    Agora, o anel de leds pode representar 3 níveis de cada emoção. Cada nível é representado por uma quantidade de leds acesa.
